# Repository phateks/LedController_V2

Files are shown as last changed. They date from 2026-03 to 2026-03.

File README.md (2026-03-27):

# LED Controller (ESP32-C3-Mini)

<table>
	<tr>
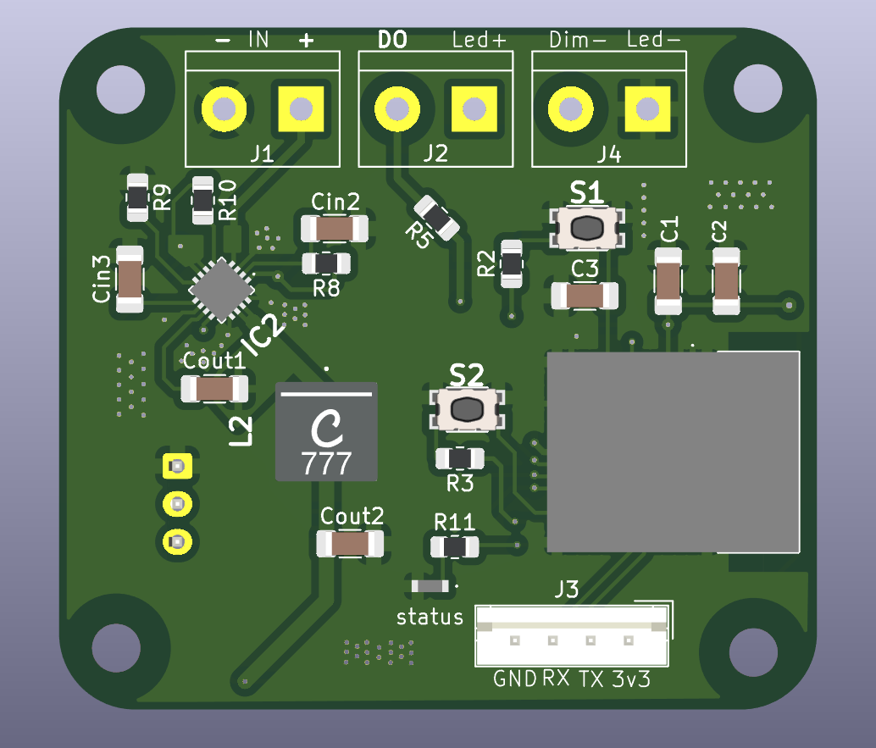
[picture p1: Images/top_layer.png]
PCB Top
		<td></td>
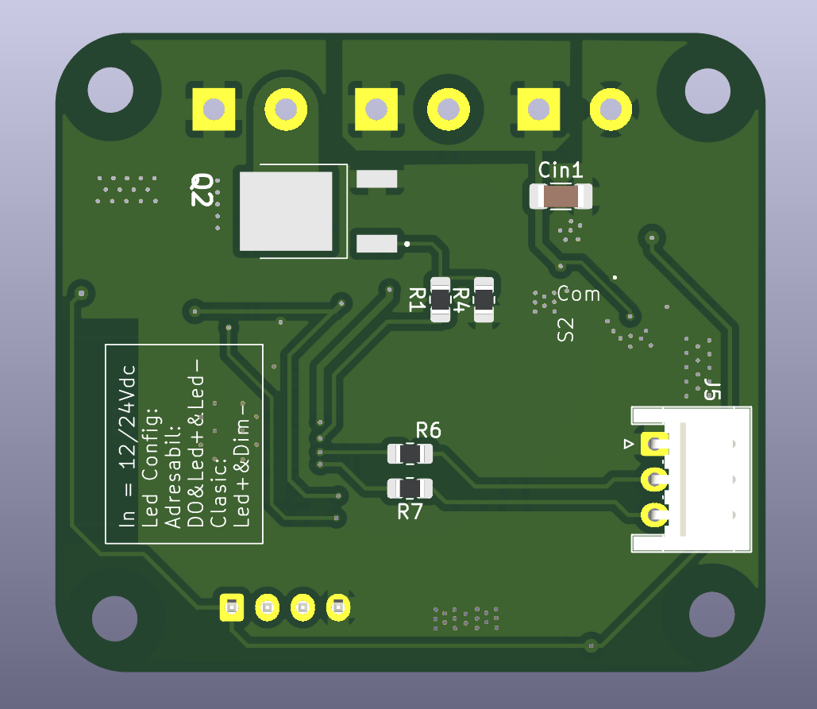
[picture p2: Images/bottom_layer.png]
PCB Bottom
		<td></td>
	</tr>
</table>

> **_NOTE:_** Add in Kicad the "desk" library 

## Power
- Input: 12 or 24 VDC on J1 connector

> **_NOTE:_** This version can run up to 5A !!

## Connections for Digital LED
- DO (DATA) 
- LED+ = VCC
- LED- = GND

## Connections for Classic LED
- LED+ = VCC
- Dim- = GND

## External Switch (Momentary)

- S1 - Dim down
- S2 - Dim up
- Com - Second connection on the switch (common for both)

## GPIO Config

- IO4: DATA LED
- IO5: PWM LED
- IO6: Dim Up
- IO7: Dim Down
- TXD0/RXD0: 
- EN: reset/enable
- BOOT: bootloader (IO09)

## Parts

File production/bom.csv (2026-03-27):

Designator | Footprint | Quantity | Value | LCSC Part #
C1, C3, COUT1 | 1206 | 3 | 100nF | C1206C104J5RAC7800
C2, CIN1 | 1206 | 2 | 10uf | KGM31HR51H106KU
CIN2, CIN3 | 1206 | 2 | 1uF | KGM31HR71H105JU
COUT2 | 1206 | 1 | 47uF | GRM31CR61A476KE15L
IC1 | ESP32C3MINI1N4X | 1 | ESP32-C3-MINI-1-N4X | ESP32-C3-MINI-1-N4X
IC2 | L6983N33QTR | 1 | L6983N33QTR | L6983N33QTR
J1, J2, J4 | TerminalBlock_bornier-2_P5.08mm | 3 | Screw_Terminal_01x02
J3 | JST_EH_B4B-EH-A_1x04_P2.50mm_Vertical | 1 | Conn_01x04_Pin
J5 | JST_EH_S3B-EH_1x03_P2.50mm_Horizontal | 1 | Conn_01x03_Pin
L2 | XAL6060472MEC | 1 | XAL6060-472MEC | XAL6060-472MEC
LED1 | 5973324507F | 1 | 5973324507F | 5973324507F
Q1 | STD120N4LF6 | 1 | STD120N4LF6
R1 | 0805 | 1 | 220ohm | AA0805FR-07220RL
R10 | 0805 | 1 | 1Mohm | RT0805FRE131ML
R11 | 0805 | 1 | 1k | MCU08050C1001FP500
R2, R3, R4, R9 | 0805 | 4 | 10k | CRCW080510K0FKEA
R5 | 0805 | 1 | 470ohm | MCU08050C4700FP500
R6, R7 | 0805 | 2 | 100ohm | RT0805FRE13100RL
R8 | 0805 | 1 | 100K | CRCW0805100KFKEA
S1, S2 | KMR_2 | 2 | KMR211G_LFS | KMR211G_LFS

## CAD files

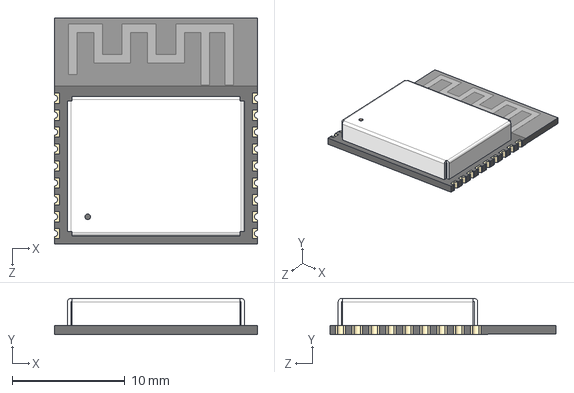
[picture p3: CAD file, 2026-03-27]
Parts/ESP32-C3-WROOM-02-N4/3D/ESP32-C3-WROOM-02-N4.stp
18.0 x 3.20 x 20.0 mm

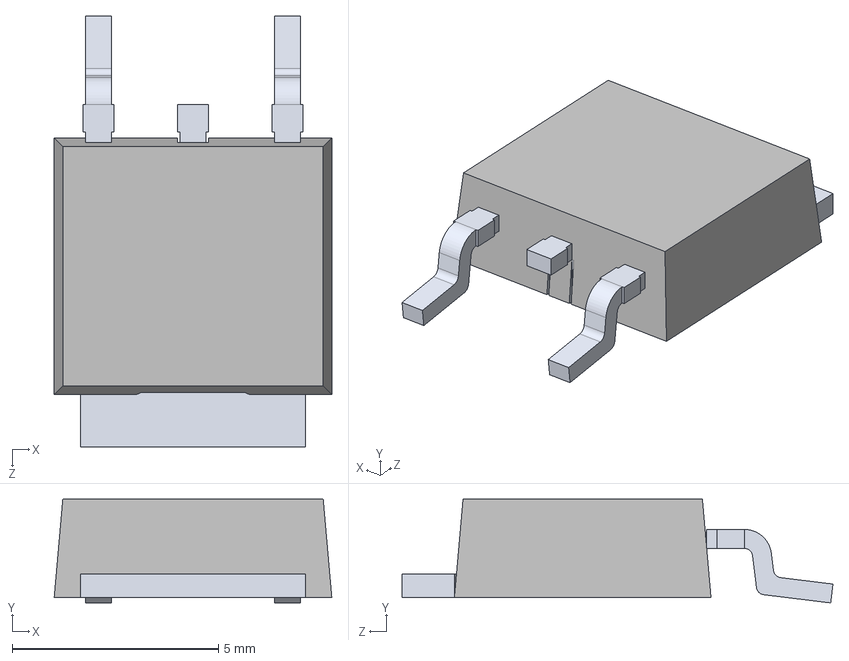
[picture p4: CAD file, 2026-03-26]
Parts/FQD13N10LTM/3D/FQD13N10LTM.stp
6.73 x 2.52 x 10.4 mm

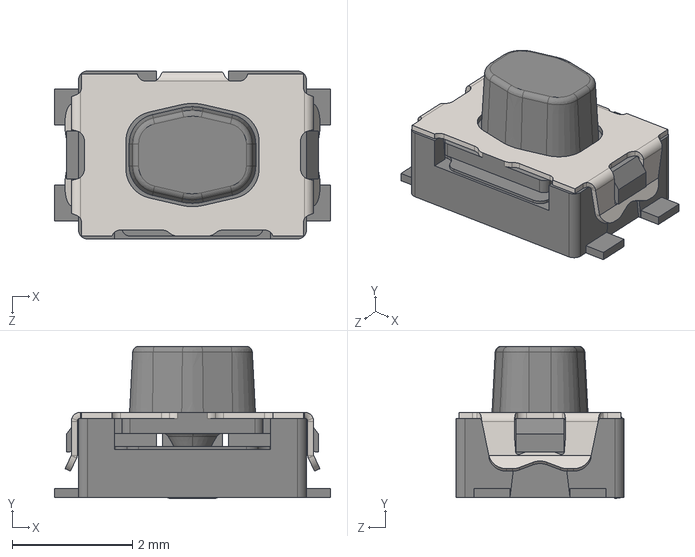
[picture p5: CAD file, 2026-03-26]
Parts/KMR211G_LFS/3D/KMR211G_LFS.stp
4.60 x 2.54 x 2.80 mm

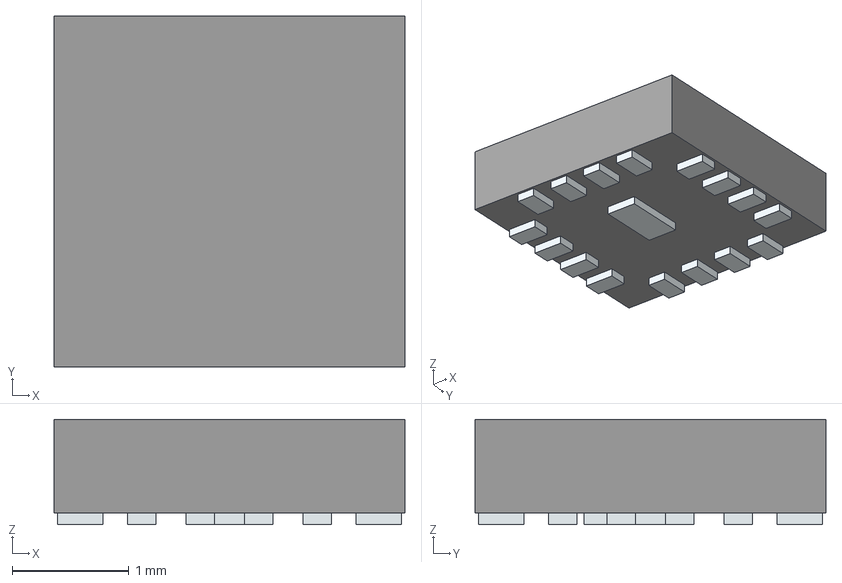
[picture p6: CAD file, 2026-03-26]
Parts/L6983N33QTR/3D/L6983N33QTR.stp
3.00 x 3.00 x 0.9 mm
Pins

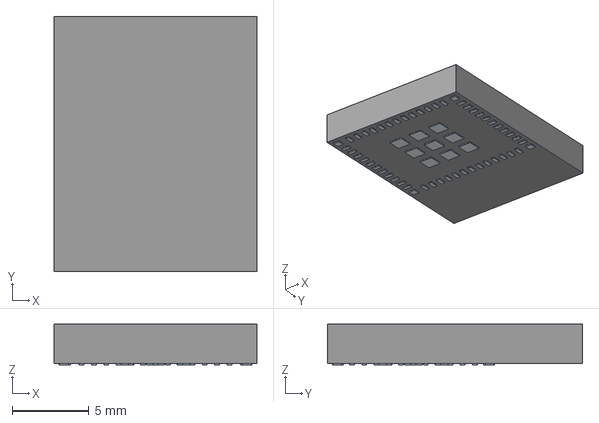
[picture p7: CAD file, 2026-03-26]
Parts/LIB_ESP32-C3-MINI-1-N4X/ESP32-C3-MINI-1-N4X/3D/ESP32-C3-MINI-1-N4X.stp
13.2 x 16.6 x 2.65 mm
Pins

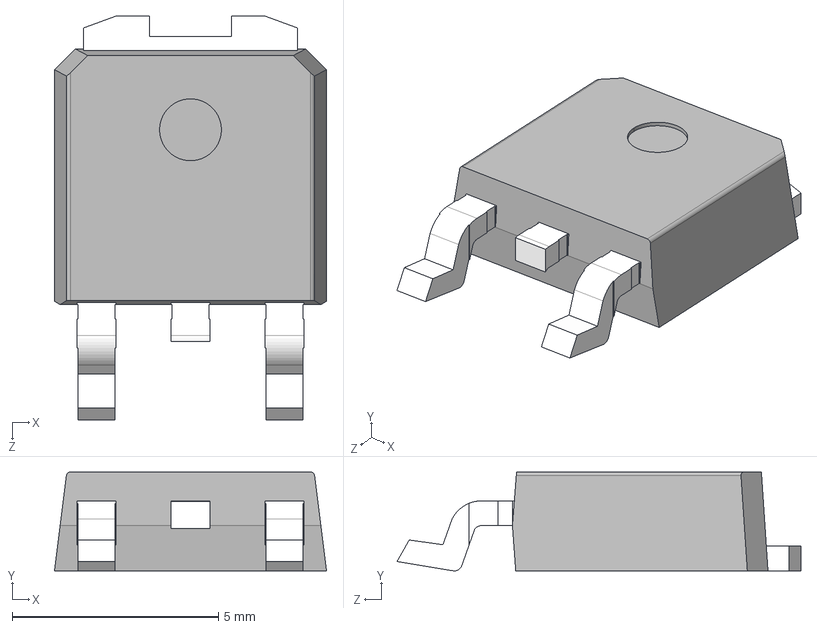
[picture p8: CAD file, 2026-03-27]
Parts/STD120N4LF6/3D/STD120N4LF6.stp
6.60 x 2.40 x 9.80 mm

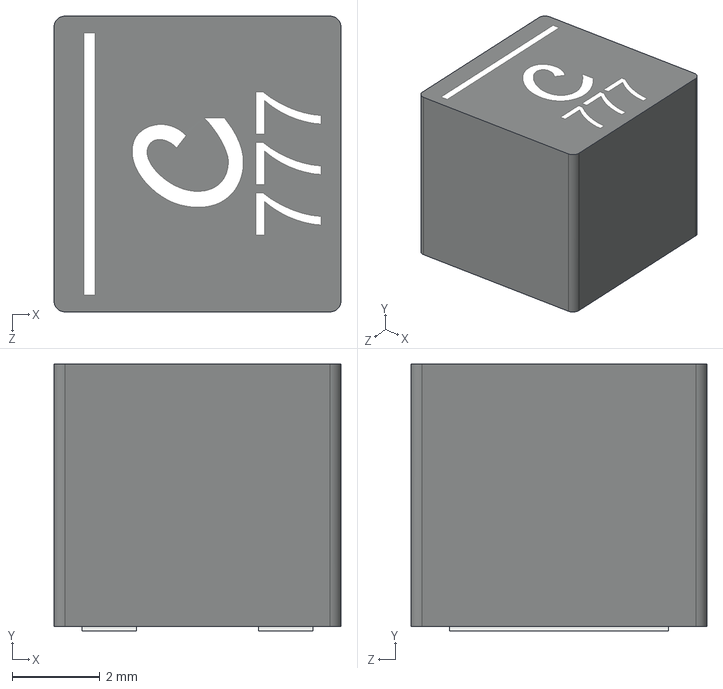
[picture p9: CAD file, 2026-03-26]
Parts/XAL6060-472MEC/3D/XAL6060-472MEC.stp
6.56 x 6.10 x 6.76 mm

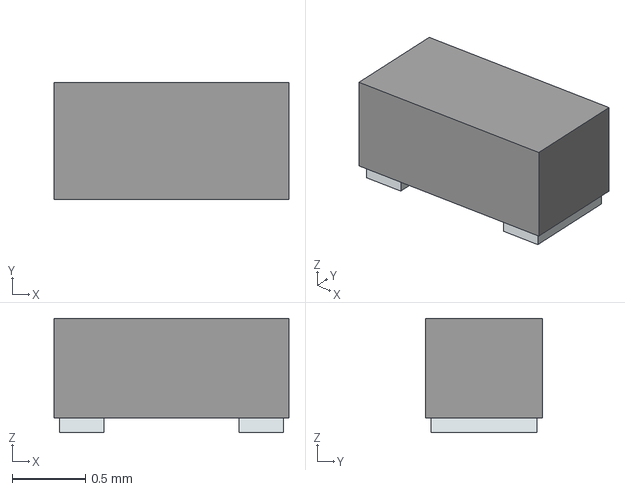
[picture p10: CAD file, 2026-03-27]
Parts/5973324507F/3D/5973324507F.stp
1.60 x 0.8 x 0.777 mm
Pins

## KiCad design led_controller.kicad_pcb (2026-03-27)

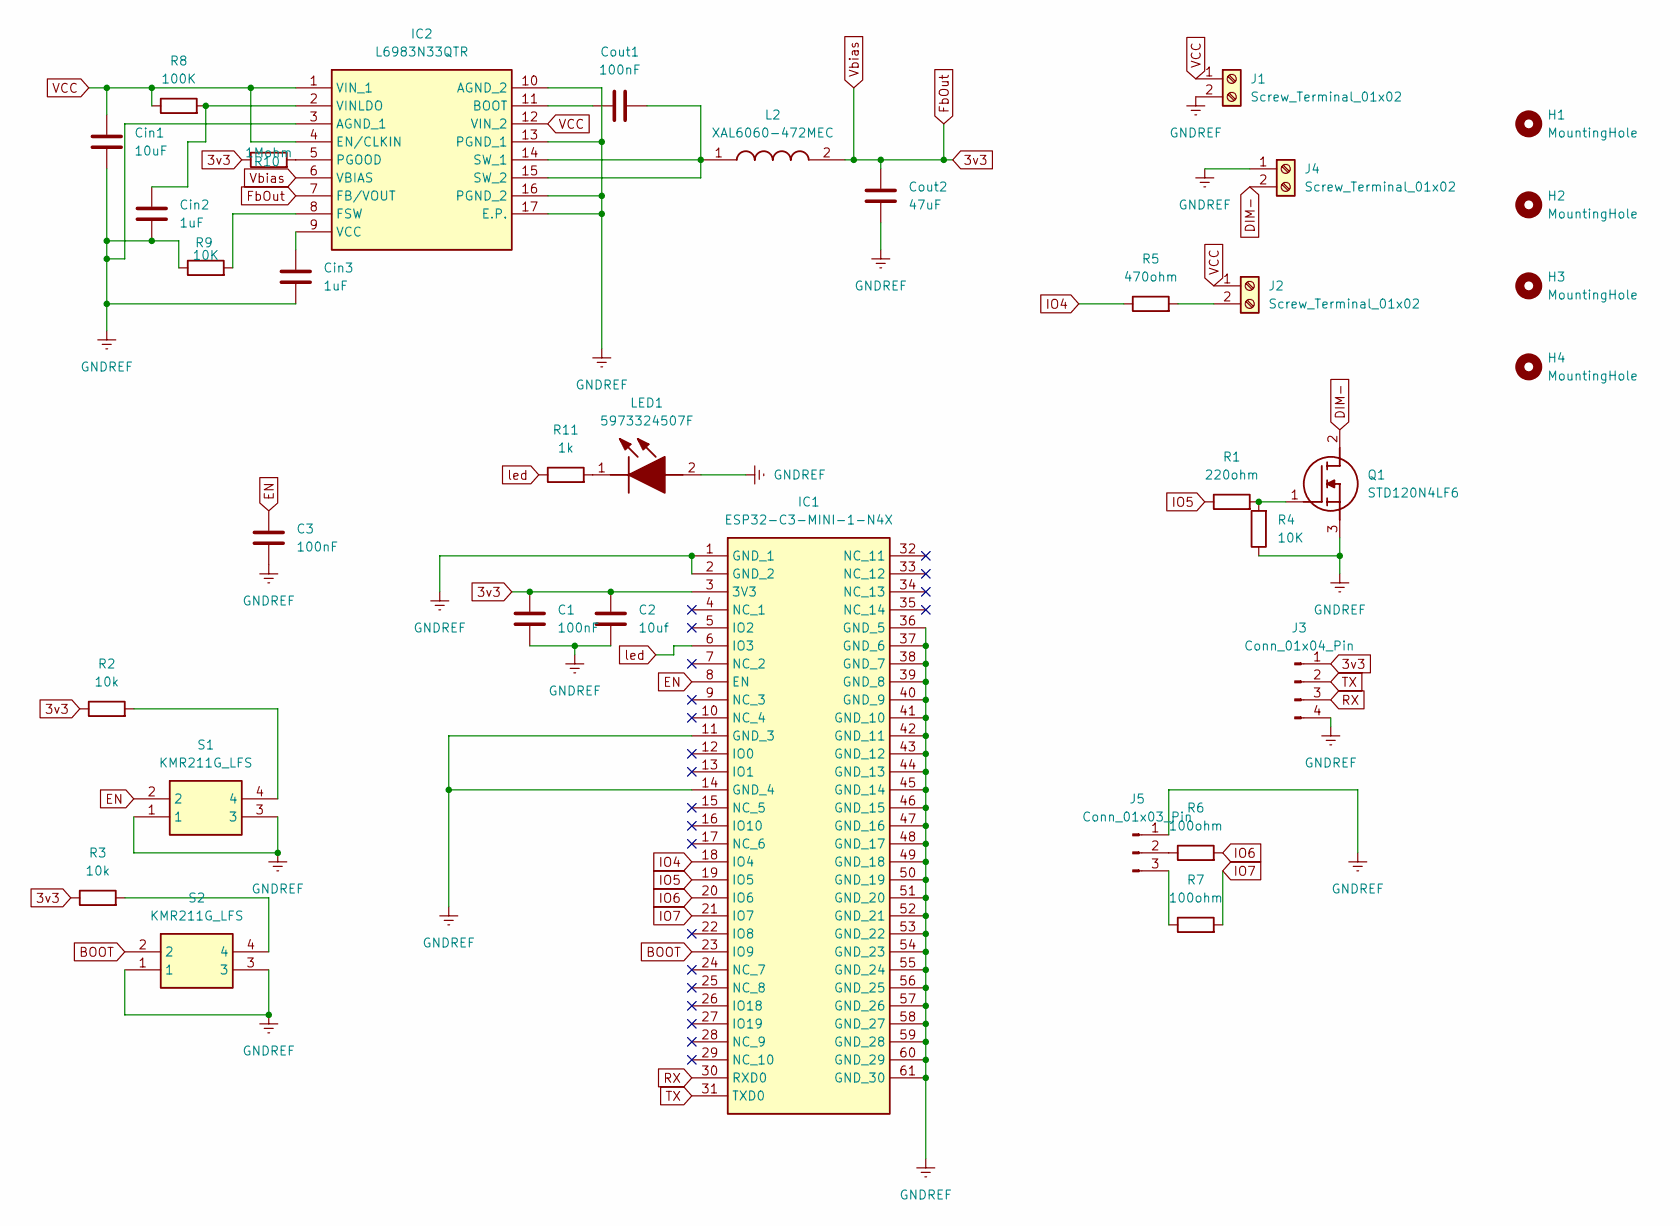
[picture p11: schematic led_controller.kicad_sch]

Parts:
C1, C3: 100nF; C_1206_3216Metric_Pad1.33x1.80mm_HandSolder
C2: 10uf; C_1206_3216Metric_Pad1.33x1.80mm_HandSolder
Cin1: 10uF; C_1206_3216Metric_Pad1.33x1.80mm_HandSolder
Cin2, Cin3: 1uF; C_1206_3216Metric_Pad1.33x1.80mm_HandSolder
Cout1: 100nF; C_1206_3216Metric_Pad1.33x1.80mm_HandSolder
Cout2: 47uF; C_1206_3216Metric_Pad1.33x1.80mm_HandSolder
H1, H2, H3, H4: MountingHole; MountingHole_3.2mm_M3
IC1: ESP32-C3-MINI-1-N4X; ESP32C3MINI1N4X; Manufacturer_Part_Number ESP32-C3-MINI-1-N4X
IC2: L6983N33QTR; Manufacturer_Part_Number L6983N33QTR; Mouser Part Number 511-L6983N33QTR
J1, J2, J4: Screw_Terminal_01x02; TerminalBlock_bornier-2_P5.08mm
J3: Conn_01x04_Pin; JST_EH_B4B-EH-A_1x04_P2.50mm_Vertical
J5: Conn_01x03_Pin; JST_EH_S3B-EH_1x03_P2.50mm_Horizontal
L2: XAL6060-472MEC; XAL6060472MEC; Manufacturer_Part_Number XAL6060-472MEC; Mouser Part Number 994-XAL6060-472MEC
LED1: 5973324507F; Manufacturer_Part_Number 5973324507F; Mouser Part Number 645-5973324507F
Q1: STD120N4LF6; Manufacturer_Part_Number STD120N4LF6; Mouser Part Number 511-STD120N4LF6
R1: 220ohm; R_0805_2012Metric_Pad1.20x1.40mm_HandSolder
R2, R3: 10k; R_0805_2012Metric_Pad1.20x1.40mm_HandSolder
R4, R9: 10K; R_0805_2012Metric_Pad1.20x1.40mm_HandSolder
R5: 470ohm; R_0805_2012Metric_Pad1.20x1.40mm_HandSolder
R6, R7: 100ohm; R_0805_2012Metric_Pad1.20x1.40mm_HandSolder
R8: 100K; R_0805_2012Metric_Pad1.20x1.40mm_HandSolder
R10: 1Mohm; R_0805_2012Metric_Pad1.20x1.40mm_HandSolder
R11: 1k; R_0805_2012Metric_Pad1.20x1.40mm_HandSolder
S1, S2: KMR211G_LFS; KMR_2; Manufacturer_Part_Number KMR211G LFS; Mouser Part Number 611-KMR211G-LFS

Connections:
3v3: C1.1, C2.1, Cout2.1, IC1.3 (3V3), IC2.6 (VBIAS), IC2.7 (FB/VOUT), J3.1, L2.2, R2.1, R3.1, R10.1
BOOT: IC1.23 (IO9), S2.2
DIM-: J4.2, Q1.2 (D)
EN: C3.1, IC1.8 (EN), S1.2
GNDREF: C1.2, C2.2, C3.2, Cin1.2, Cin2.2, Cin3.2, Cout2.2, IC1.1 (GND_1), IC1.2 (GND_2), IC1.11 (GND_3), IC1.14 (GND_4), IC1.36 (GND_5), IC1.37 (GND_6), IC1.38 (GND_7), IC1.39 (GND_8), IC1.40 (GND_9), IC1.41 (GND_10), IC1.42 (GND_11), IC1.43 (GND_12), IC1.44 (GND_13), IC1.45 (GND_14), IC1.46 (GND_15), IC1.47 (GND_16), IC1.48 (GND_17), IC1.49 (GND_18), IC1.50 (GND_19), IC1.51 (GND_20), IC1.52 (GND_21), IC1.53 (GND_22), IC1.54 (GND_23), IC1.55 (GND_24), IC1.56 (GND_25), IC1.57 (GND_26), IC1.58 (GND_27), IC1.59 (GND_28), IC1.60 (GND_29), IC1.61 (GND_30), IC2.3 (AGND_1), IC2.10 (AGND_2), IC2.13 (PGND_1), IC2.16 (PGND_2), IC2.17 (E.P.), J1.2, J3.4, J4.1, J5.1, LED1.2 (A), Q1.3 (S), R4.1, R9.1, S1.1, S1.3, S2.1, S2.3
IO4: IC1.18 (IO4), R5.1
IO5: IC1.19 (IO5), R1.1
IO6: IC1.20 (IO6), R6.2
IO7: IC1.21 (IO7), R7.2
unnamed: Cout1.1, IC2.11 (BOOT)
unnamed: IC2.8 (FSW), R9.2
unnamed: IC2.5 (PGOOD), R10.2
unnamed: Cout1.2, IC2.14 (SW_1), IC2.15 (SW_2), L2.1
unnamed: Cin3.1, IC2.9 (VCC)
unnamed: Cin2.1, IC2.2 (VINLDO), R8.2
unnamed: J2.2, R5.2
unnamed: J5.2, R6.1
unnamed: J5.3, R7.1
unnamed: LED1.1 (K), R11.2
unnamed: Q1.1 (G), R1.2, R4.2
unnamed: R2.2, S1.4
unnamed: R3.2, S2.4
RX: IC1.30 (RXD0), J3.3
TX: IC1.31 (TXD0), J3.2
VCC: Cin1.1, IC2.1 (VIN_1), IC2.4 (EN/CLKIN), IC2.12 (VIN_2), J1.1, J2.1, R8.1
led: IC1.6 (IO3), R11.1

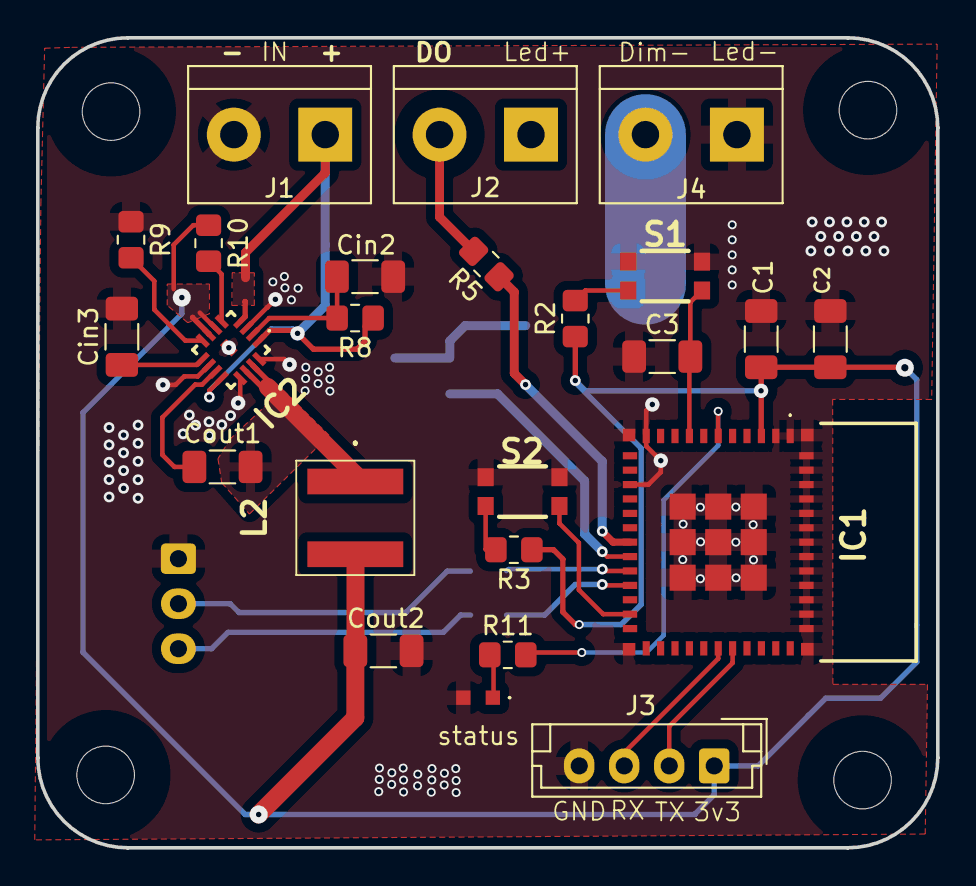
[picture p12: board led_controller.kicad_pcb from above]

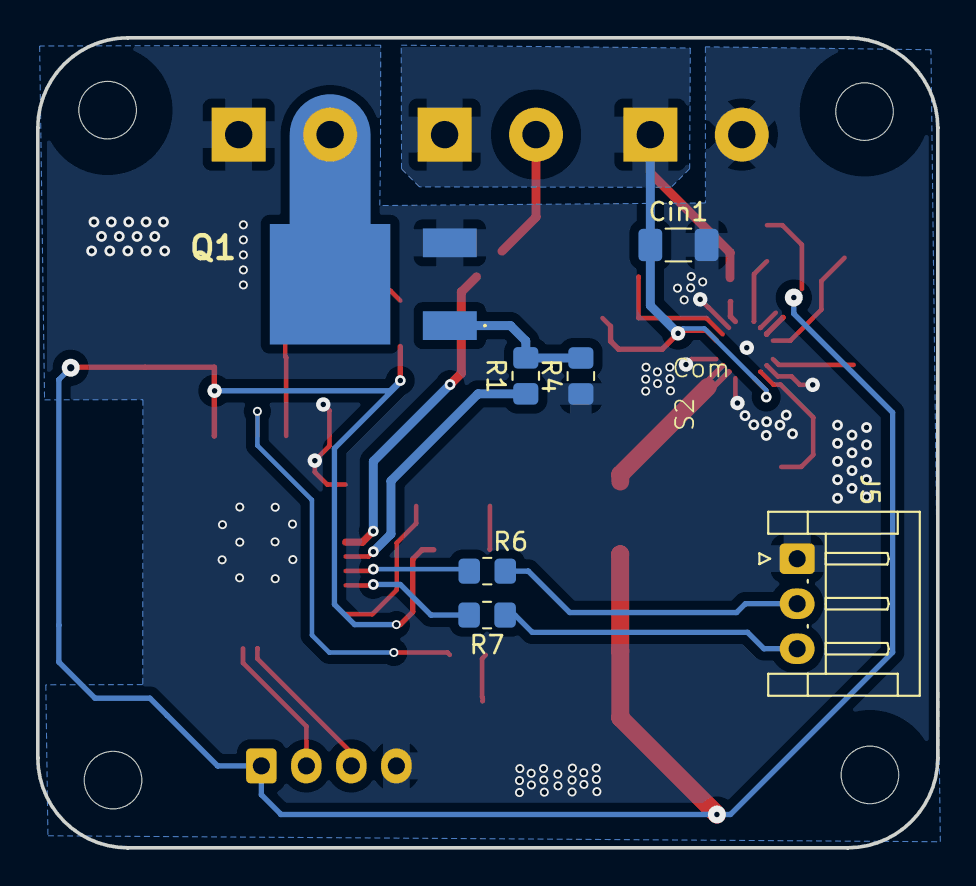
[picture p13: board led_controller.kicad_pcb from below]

Board: 2 copper layers, 50.0 x 45.0 mm, 35 parts (7 on the bottom side), 26 nets.
